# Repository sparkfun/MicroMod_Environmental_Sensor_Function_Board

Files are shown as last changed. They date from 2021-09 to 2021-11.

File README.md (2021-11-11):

SparkFun MicroMod Environmental Sensor Function Board
========================================

SparkFun MicroMod Environmental Sensor Function Board (https://www.sparkfun.com/products/18632)

[*SparkFun MicroMod Environmental Sensor Function Board (SEN-18632)*](https://www.sparkfun.com/products/18632)

The SparkFun MicroMod Environmental Function Board adds additional sensing options to the MicroMod Processor Boards. This Function Board includes three sensors to monitor air quality (SGP40), humidity & temperature (SHTC3), and CO<sub>2</sub> concentrations (STC31) in your indoor environment. To make it even easier to use, all communication is over the MicroMod's I<sup>2</sup>C bus!

* The SGP40 measures the quality of the air in your room or house. The SGP40 uses a metal oxide (MOx) sensor with a temperature controlled micro hotplate and provides a humidity-compensated volatile organic compound (VOC) based indoor air quality signal. Both the sensing element and VOC Algorithm feature an unmatched robustness against contaminating gases present in real world applications enabling a unique long term stability as well as low drift and device to device variation.

* The SHTC3 is a highly accurate digital humidity and temperature sensor. The SHTC3 uses a capacitive humidity sensor with a relative humidity measurement range of 0 to 100% RH and bandgap temperature sensor with a temperature measurement range of -40&deg;C to 125&deg;C. The SHTC3 builds on the success of their SHTC1 sensor with higher accuracy (±2% RH, ±0.2&deg;C) than its predecessor, enabling greater flexibility.

* The STC31 measures CO<sub>2</sub> concentrations based on thermal conductivity and has two CO<sub>2</sub> measurement ranges: 0 to 25 vol%; and 0 to 100 vol%. The measurement repeatability is 0.2 vol%, with a stability of 0.025 vol% / °C. The measurement accuracy depends on the measurement range: 0.5 vol% + 3% measured value; 1 vol% + 3% measured value. Using measurements from the SHTC3, the STC31 is able to provide humidity-compensated measurements together with improved temperature compensation.  The STC31 can compensate for atmospheric pressure too - which is handy if, like us, you’re up in the mountains!

The outstanding performance of these three sensors is based on Sensirion’s patented CMOSens<sup>&reg;</sup> technology, which combines the sensor element, signal processing, and digital calibration on a small CMOS chip. The well-proven CMOS technology is perfectly suited for high-quality mass production and is the ideal choice for demanding and cost-sensitive OEM applications.

Utilizing our handy M.2 MicroMod connector, no soldering is required to connect it to your system. Simply match up the key on your processor and function board's beveled edge connector to their respective key on the M.2 connector, then secure them to the main board with screws. The MicroMod Environmental Function Board can then be read via the I<sup>2</sup>C port. The board is equipped with the AP2112 3.3V voltage regulator, I<sup>2</sup>C pull-up resistors, power LED, jumper to disable the LED, and jumpers for alternative STC31 addresses. 

Repository Contents
-------------------

* **/Firmware** - Arduino example code from the tutorial
* **/Hardware** - Eagle design files (.brd, .sch)
* **/Production** - Production panel files (.brd)

Documentation
--------------

* **[Installing an Arduino Library Guide](https://learn.sparkfun.com/tutorials/installing-an-arduino-library/all)** - Basic information on how to install an Arduino library.
* **Arduino Libraries**
  * **[SGP40](https://github.com/sparkfun/SparkFun_SGP40_Arduino_Library)**
  * **[SHTC3](https://github.com/sparkfun/SparkFun_SHTC3_Arduino_Library)**
  * **[STC3X](https://github.com/sparkfun/SparkFun_STC3x_Arduino_Library)**
* **[Hookup Guide](https://learn.sparkfun.com/tutorials/2001)** - Basic hookup guide

Product Versions
----------------

* [SEN-18632](https://www.sparkfun.com/products/18632)- Initial release

Version History
---------------

* v1.0 - Initial Release

License Information
-------------------

This product is _**open source**_! 

Please review the LICENSE.md file for license information. 

If you have any questions or concerns on licensing, please contact technical support on our [SparkFun forums](https://forum.sparkfun.com/viewforum.php?f=152).

Distributed as-is; no warranty is given.

- Your friends at SparkFun.

_<COLLABORATION CREDIT>_

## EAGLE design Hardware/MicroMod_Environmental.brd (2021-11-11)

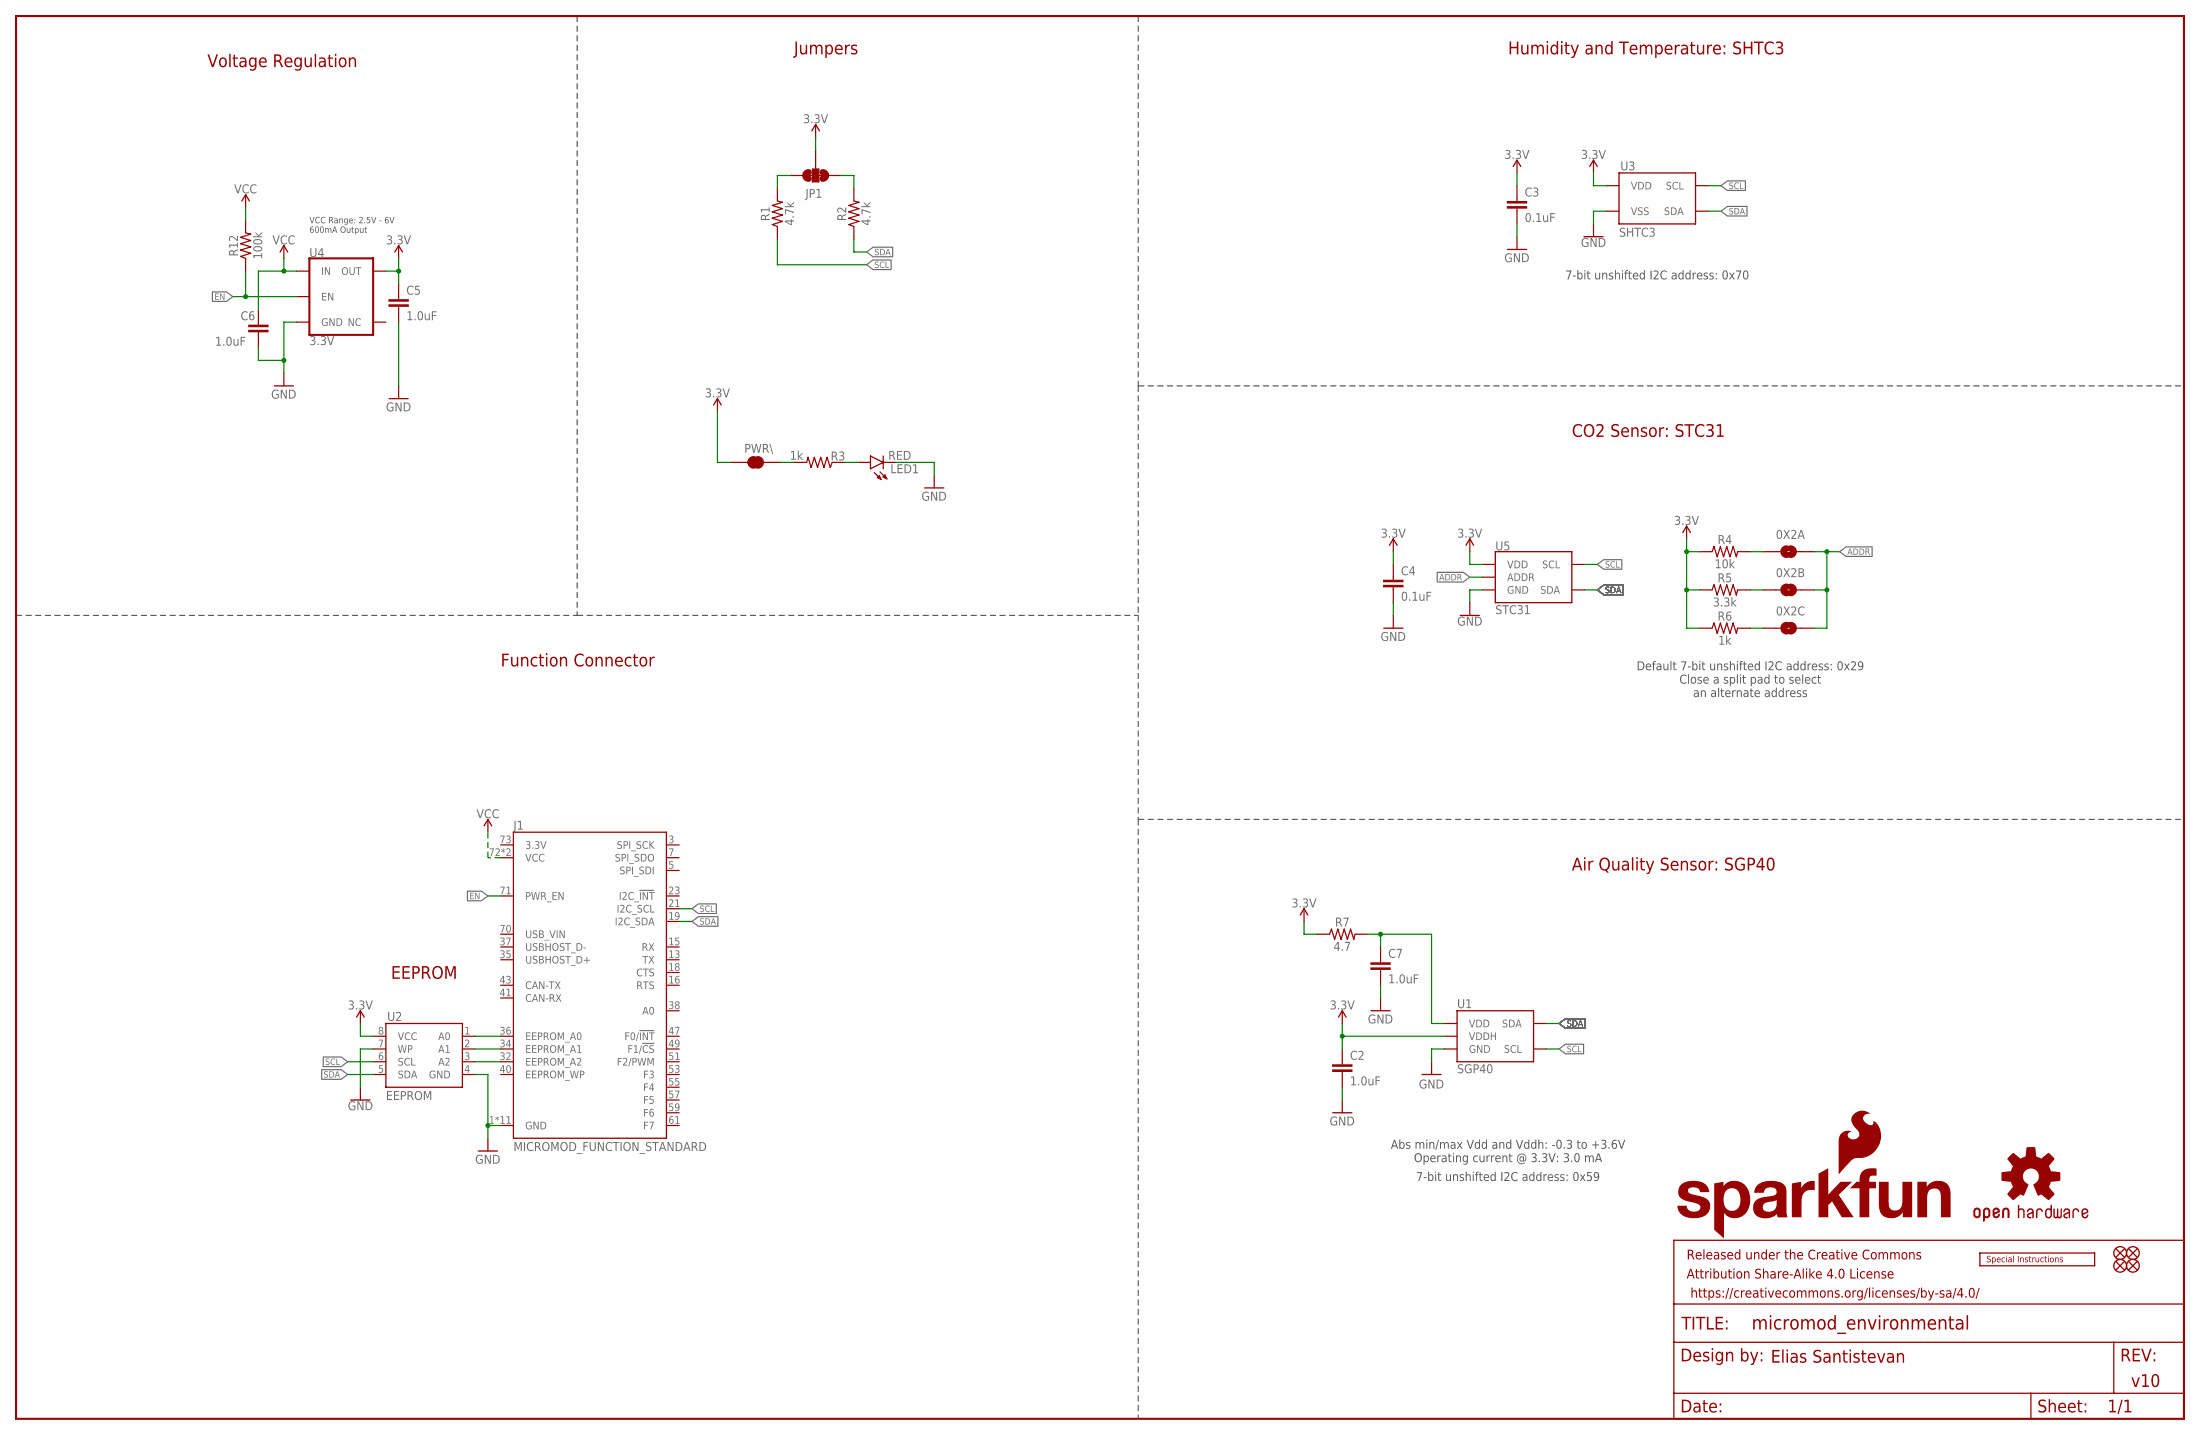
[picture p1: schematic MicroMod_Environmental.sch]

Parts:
0X2A, 0X2B, 0X2C: JUMPER-SMT_2_NO_SILK; SMT-JUMPER_2_NO_SILK
C2, C5, C6, C7: 1.0uF; 0603
C3, C4: 0.1uF; 0603
FD1, FD2, FD3, FD4: FIDUCIAL1X2; FIDUCIAL-1X2
FRAME1: FRAME-LEDGER; CREATIVE_COMMONS
J1: MICROMOD_FUNCTION_STANDARD; M.2-CARD-E-22_FUNCTION_STANDARD
JP1: JUMPER-SMT_3_2-NC_TRACE_SILK; SMT-JUMPER_3_2-NC_TRACE_SILK
LED1: RED; LED-0603
LOGO1: SFE_LOGO_NAME_FLAME.2_INCH; SFE_LOGO_NAME_FLAME_.2
LOGO2: OSHW-LOGOS; OSHW-LOGO-S
LOGO3: SPECIAL_INSTRUCTIONS-ORDERING; ORDERING_INSTRUCTIONS
PWR\: JUMPER-SMT_2_NC_TRACE_SILK; SMT-JUMPER_2_NC_TRACE_SILK
R1, R2: 4.7k; 0603
R3, R6: 1k; 0603
R4: 10k; 0603
R5: 3.3k; 0603
R7: 4.7; 0603
R12: 100k; 0603
U1: SGP40
U2: EEPROM; SO08
U3: SHTC3
U4: 3.3V; SOT23-5
U5: STC31

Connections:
3.3V: C2.1, C3.1, C4.1, C5.1, JP1.2, PWR\.2, R4.1, R5.1, R6.1, R7.1, U1.5 (VDDH), U2.8 (VCC), U3.1 (VDD), U4.5 (OUT), U5.6 (VDD)
A0: J1.36 (EEPROM_A0), U2.1 (A0)
A1: J1.34 (EEPROM_A1), U2.2 (A1)
A2: J1.32 (EEPROM_A2), U2.3 (A2)
ADDR: 0X2A.2, 0X2B.2, 0X2C.2, U5.3 (ADDR)
EN: J1.71 (PWR_EN), R12.1, U4.3 (EN)
GND: C2.2, C3.2, C4.2, C5.2, C6.2, C7.2, J1.1 (GND), J1.33 (GND), J1.39 (GND), J1.45 (GND), J1.75 (GND), J1.GND1 (GND), J1.GND2 (GND), J1.GND3 (GND), J1.GND4 (GND), J1.GND5 (GND), J1.GND6 (GND), LED1.C, U1.2 (GND), U1.4 (GND), U1.DIEPAD (GND), U2.4 (GND), U2.7 (WP), U3.4 (VSS), U3.5 (VSS), U4.2 (GND), U5.1 (GND), U5.5 (GND), U5.9 (GND), U5.11 (GND), U5.DIEPAD (GND)
unnamed: PWR\.1, R3.2
unnamed: C7.1, R7.2, U1.1 (VDD)
unnamed: JP1.3, R1.2
unnamed: JP1.1, R2.2
unnamed: 0X2A.1, R4.2
unnamed: 0X2B.1, R5.2
unnamed: 0X2C.1, R6.2
unnamed: LED1.A, R3.1
SCL: J1.21 (I2C_SCL), R1.1, U1.6 (SCL), U2.6 (SCL), U3.2 (SCL), U5.4 (SCL)
SDA: J1.19 (I2C_SDA), R2.1, U1.3 (SDA), U2.5 (SDA), U3.3 (SDA), U5.7 (SDA)
VCC: C6.1, J1.72 (VCC), J1.74 (VCC), R12.2, U4.1 (IN)

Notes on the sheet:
Elias Santistevan
v10
VCC Range: 2.5V - 6V 600mA Output
Default 7-bit unshifted I2C address: 0x29 Close a split pad to select an alternate address
7-bit unshifted I2C address: 0x70
7-bit unshifted I2C address: 0x59
Abs min/max Vdd and Vddh: -0.3 to +3.6V Operating current @ 3.3V: 3.0 mA
EEPROM
Voltage Regulation
Jumpers
Humidity and Temperature: SHTC3
CO2 Sensor: STC31
Function Connector
Air Quality Sensor: SGP40

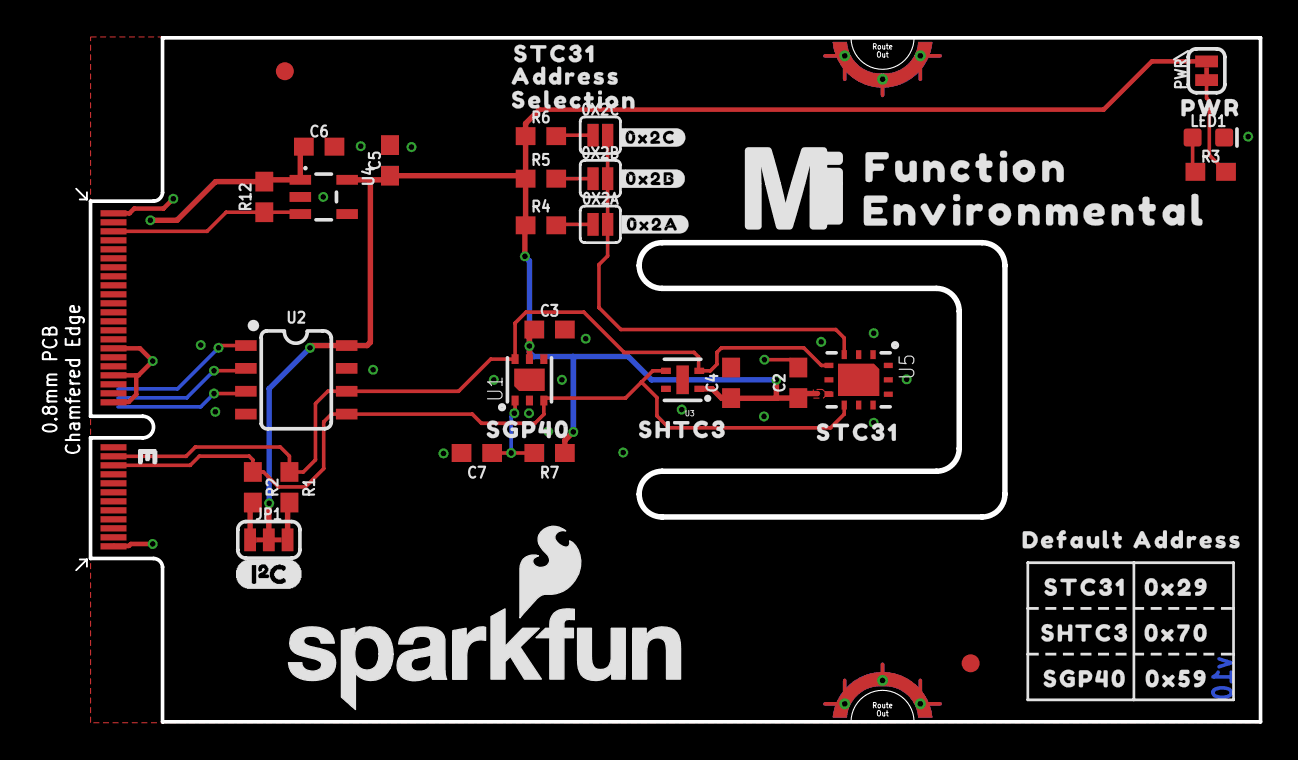
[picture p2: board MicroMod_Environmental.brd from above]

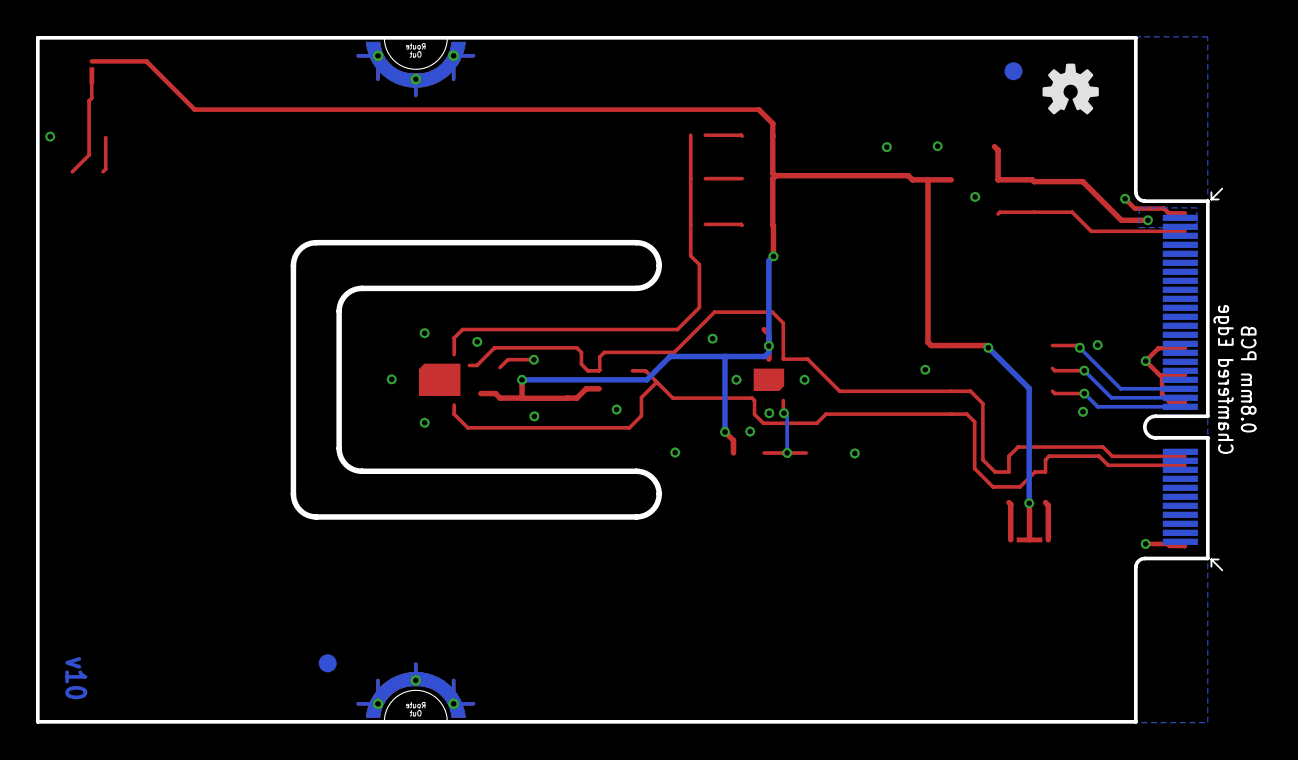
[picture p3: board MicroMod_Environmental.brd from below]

Board: 2 copper layers, 65.8 x 38.0 mm, 56 parts (3 on the bottom side), 18 nets.

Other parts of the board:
U$1: #0X2A#21
U$2: #0X2B#21
U$3: #0X2C#21
U$4: PWR321541
U$5: FUNCTION524
U$6: ENVIRONMENTAL526
U$7: MICROMOD_MI_LOGO_1
U$8: I2C
U$9, U$15: ADDRESS40313505
U$10: 0X2940313520
U$11, U$18: SGP40313503
U$12, U$17: SHTC3501
U$13, U$16, U$22: STC313502
U$14: DEFAULT40313504
U$19: 0X5940313520
U$20: 0X7040313520
U$21: SELECTION40313506

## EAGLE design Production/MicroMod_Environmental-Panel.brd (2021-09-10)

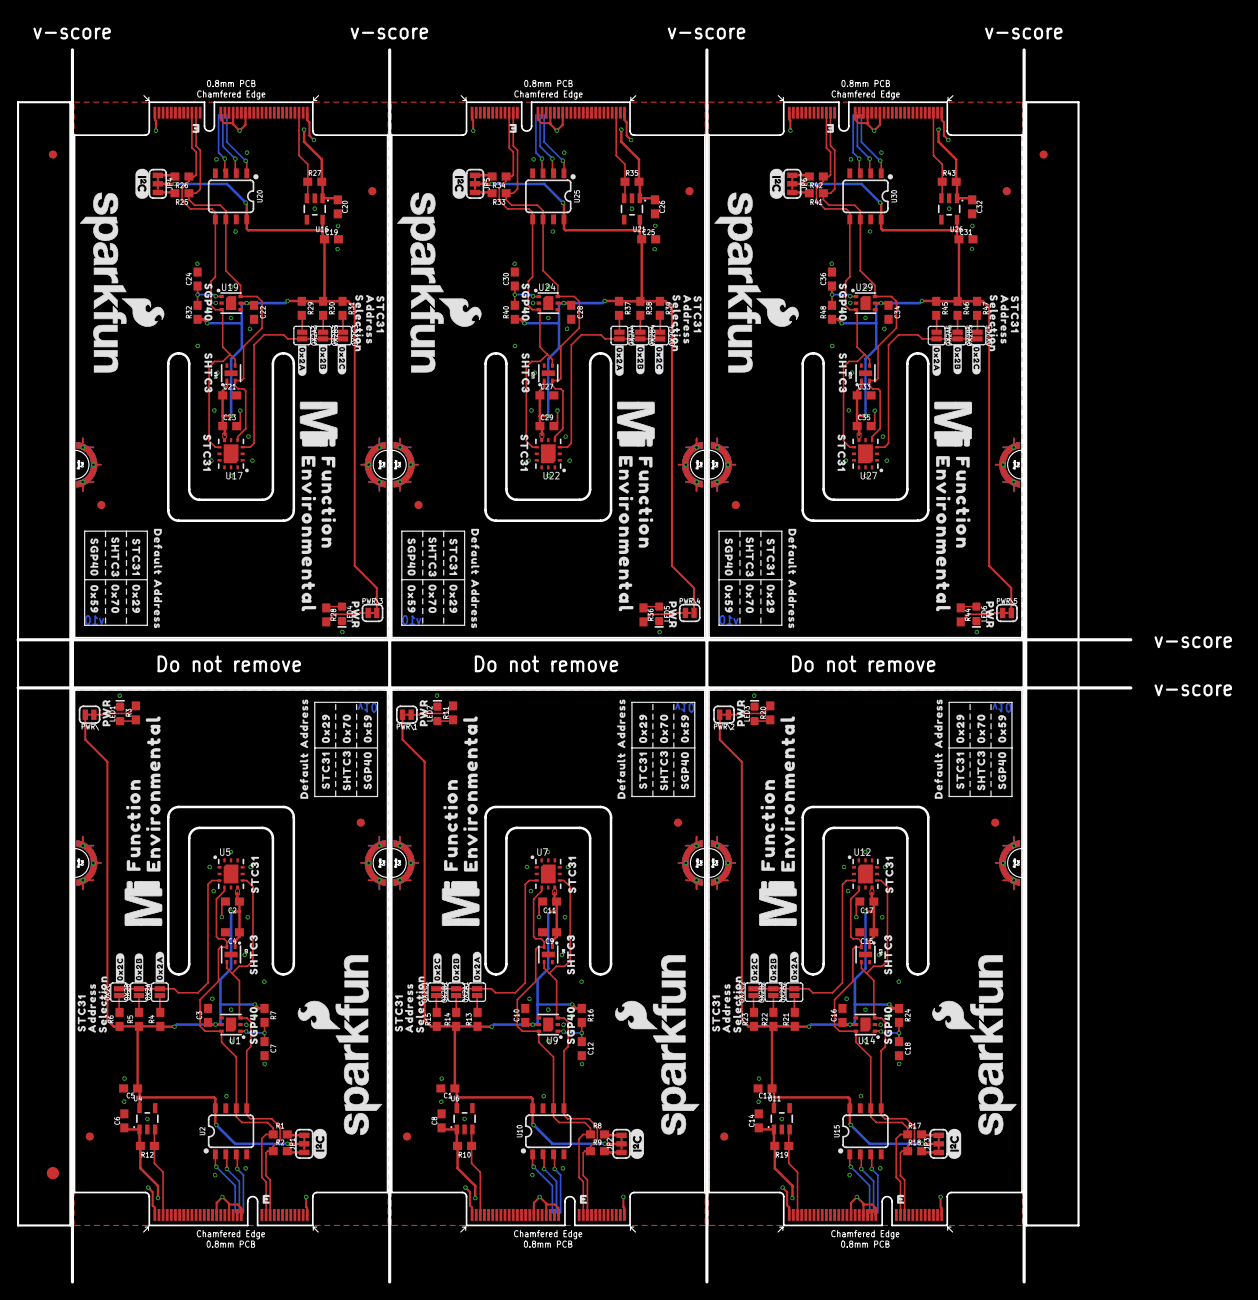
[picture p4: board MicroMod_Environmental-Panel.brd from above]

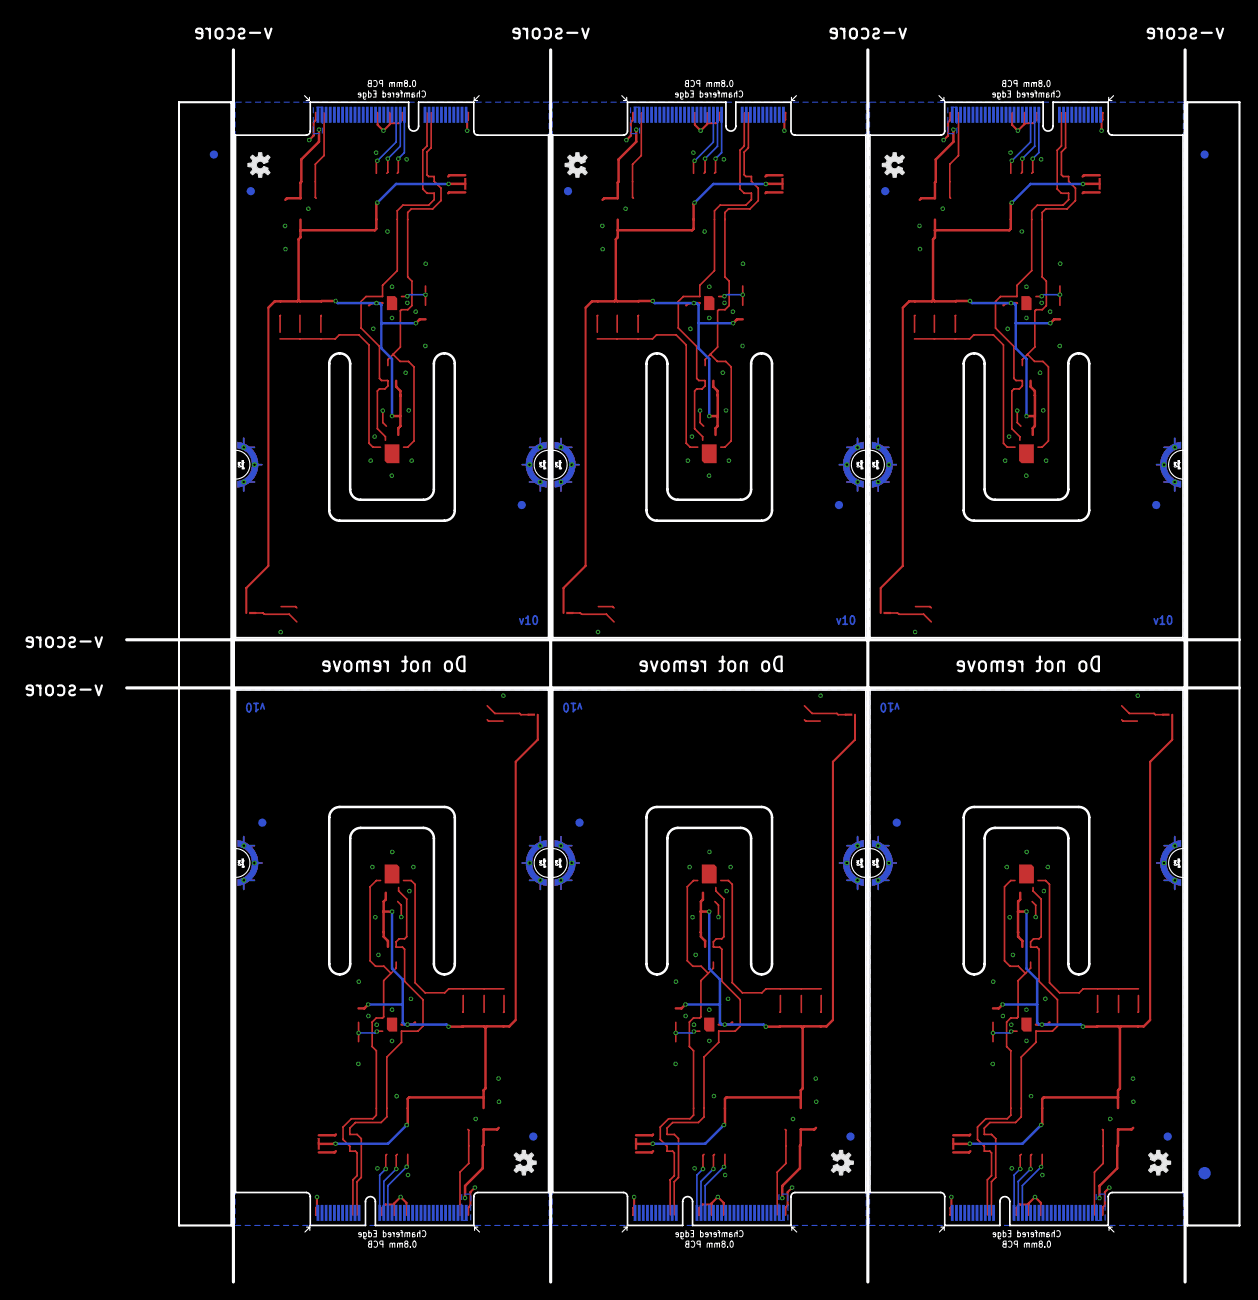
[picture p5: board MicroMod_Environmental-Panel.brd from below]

Board: 2 copper layers, 135.1 x 149.6 mm, 330 parts (21 on the bottom side), 108 nets.

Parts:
0X2A, 0X2A1, 0X2A2, 0X2A3, 0X2A4, 0X2A5, 0X2B, 0X2B1, 0X2B2, 0X2B3, 0X2B4, 0X2B5, 0X2C, 0X2C1, 0X2C2, 0X2C3, 0X2C4, 0X2C5: JUMPER-SMT_2_NO_SILK; SMT-JUMPER_2_NO_SILK
C1, C2, C5, C6, C7, C8, C11, C12, C13, C14, C17, C18, C19, C20, C23, C24, C25, C26, C29, C30, C31, C32, C35, C36: 1.0uF; 0603
C3, C4, C9, C10, C15, C16, C21, C22, C27, C28, C33, C34: 0.1uF; 0603
E$1, E$2, E$3, E$4: FIDUCIAL-1X2
E$5, E$6: FIDUCIAL-1.5X3
FD1, FD2, FD3, FD4, FD5, FD6, FD7, FD8, FD9, FD10, FD11, FD12, FD13, FD14, FD15, FD16, FD17, FD18, FD19, FD20, FD21, FD22, FD23, FD24: FIDUCIAL1X2; FIDUCIAL-1X2
J1, J2, J3, J4, J5, J6: MICROMOD_STANDARD; M.2-CARD-E-22_FUNCTION_STANDARD
JP1, JP2, JP3, JP4, JP5, JP6: JUMPER-SMT_3_2-NC_TRACE_SILK; SMT-JUMPER_3_2-NC_TRACE_SILK
LED1, LED2, LED3, LED4, LED5, LED6: RED; LED-0603
LOGO1, LOGO3, LOGO5, LOGO7, LOGO9, LOGO11: SFE_LOGO_NAME_FLAME.2_INCH; SFE_LOGO_NAME_FLAME_.2
LOGO2, LOGO4, LOGO6, LOGO8, LOGO10, LOGO12: OSHW-LOGOS; OSHW-LOGO-S
PWR\, PWR\1, PWR\2, PWR\3, PWR\4, PWR\5: JUMPER-SMT_2_NC_TRACE_SILK; SMT-JUMPER_2_NC_TRACE_SILK
R1, R2, R8, R9, R17, R18, R25, R26, R33, R34, R41, R42: 4.7k; 0603
R3, R6, R11, R15, R20, R23, R28, R31, R36, R39, R44, R47: 1k; 0603
R4, R13, R21, R29, R37, R45: 10k; 0603
R5, R14, R22, R30, R38, R46: 3.3k; 0603
R7, R16, R24, R32, R40, R48: 4.7; 0603
R10, R12, R19, R27, R35, R43: 100k; 0603
U1, U9, U14, U19, U24, U29: SGP40
U2, U10, U15, U20, U25, U30: EEPROM; SO08
U3, U8, U13, U18, U23, U28: SHTC3
U4, U6, U11, U16, U21, U26: 3.3V; SOT23-5
U5, U7, U12, U17, U22, U27: STC31
U$1, U$23, U$45, U$67, U$89, U$111: #0X2A#21
U$2, U$24, U$46, U$68, U$90, U$112: #0X2B#21
U$3, U$25, U$47, U$69, U$91, U$113: #0X2C#21
U$4, U$26, U$48, U$70, U$92, U$114: PWR321541
U$5, U$27, U$49, U$71, U$93, U$115: FUNCTION524
U$6, U$28, U$50, U$72, U$94, U$116: ENVIRONMENTAL526
U$7, U$29, U$51, U$73, U$95, U$117: MICROMOD_MI_LOGO_1
U$8, U$30, U$52, U$74, U$96, U$118: I2C
U$9, U$15, U$35, U$42, U$57, U$64, U$79, U$86, U$101, U$108, U$123, U$130: ADDRESS40313505
U$10, U$39, U$61, U$83, U$105, U$127: 0X2940313520
U$11, U$18, U$31, U$38, U$53, U$60, U$75, U$82, U$97, U$104, U$119, U$126: SGP40313503
U$12, U$17, U$32, U$37, U$54, U$59, U$76, U$81, U$98, U$103, U$120, U$125: SHTC3501
U$13, U$16, U$22, U$33, U$36, U$44, U$55, U$58, U$66, U$77, U$80, U$88, U$99, U$102, U$110, U$121, U$124, U$132: STC313502
U$14, U$34, U$56, U$78, U$100, U$122: DEFAULT40313504
U$19, U$40, U$62, U$84, U$106, U$128: 0X5940313520
U$20, U$41, U$63, U$85, U$107, U$129: 0X7040313520
U$21, U$43, U$65, U$87, U$109, U$131: SELECTION40313506

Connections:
3.3V: C2.1, C3.1, C4.1, C5.1, JP1.2, PWR\.2, R4.1, R5.1, R6.1, R7.1, U1.5, U2.8, U3.1, U4.5, U5.6
3.3V1: C1.1, C9.1, C10.1, C11.1, JP2.2, PWR\1.2, R13.1, R14.1, R15.1, R16.1, U6.5, U7.6, U8.1, U9.5, U10.8
3.3V2: C13.1, C15.1, C16.1, C17.1, JP3.2, PWR\2.2, R21.1, R22.1, R23.1, R24.1, U11.5, U12.6, U13.1, U14.5, U15.8
3.3V3: C19.1, C21.1, C22.1, C23.1, JP4.2, PWR\3.2, R29.1, R30.1, R31.1, R32.1, U16.5, U17.6, U18.1, U19.5, U20.8
3.3V4: C25.1, C27.1, C28.1, C29.1, JP5.2, PWR\4.2, R37.1, R38.1, R39.1, R40.1, U21.5, U22.6, U23.1, U24.5, U25.8
3.3V5: C31.1, C33.1, C34.1, C35.1, JP6.2, PWR\5.2, R45.1, R46.1, R47.1, R48.1, U26.5, U27.6, U28.1, U29.5, U30.8
A0: J1.36, U2.1
A1: J1.34, U2.2
A2: J1.32, U2.3
A3: J2.36, U10.1
A4: J2.32, U10.3
A5: J2.34, U10.2
A6: J3.36, U15.1
A7: J3.32, U15.3
A8: J3.34, U15.2
A9: J4.36, U20.1
A10: J4.32, U20.3
A11: J4.34, U20.2
A12: J5.36, U25.1
A13: J5.32, U25.3
A14: J5.34, U25.2
A15: J6.36, U30.1
A16: J6.32, U30.3
A17: J6.34, U30.2
ADDR: 0X2A.2, 0X2B.2, 0X2C.2, U5.3
ADDR1: 0X2A1.2, 0X2B1.2, 0X2C1.2, U7.3
ADDR2: 0X2A2.2, 0X2B2.2, 0X2C2.2, U12.3
ADDR3: 0X2A3.2, 0X2B3.2, 0X2C3.2, U17.3
ADDR4: 0X2A4.2, 0X2B4.2, 0X2C4.2, U22.3
ADDR5: 0X2A5.2, 0X2B5.2, 0X2C5.2, U27.3
EN: J1.71, R12.1, U4.3
EN1: J2.71, R10.1, U6.3
EN2: J3.71, R19.1, U11.3
EN3: J4.71, R27.1, U16.3
EN4: J5.71, R35.1, U21.3
EN5: J6.71, R43.1, U26.3
GND: C2.2, C3.2, C4.2, C5.2, C6.2, C7.2, J1.1, J1.33, J1.39, J1.45, J1.75, J1.GND1, J1.GND2, J1.GND3, J1.GND4, J1.GND5, J1.GND6, LED1.C, U1.2, U1.4, U1.DIEPAD, U2.4, U2.7, U3.4, U3.5, U4.2, U5.1, U5.5, U5.9, U5.11, U5.DIEPAD
GND1: C1.2, C8.2, C9.2, C10.2, C11.2, C12.2, J2.1, J2.33, J2.39, J2.45, J2.75, J2.GND1, J2.GND2, J2.GND3, J2.GND4, J2.GND5, J2.GND6, LED2.C, U6.2, U7.1, U7.5, U7.9, U7.11, U7.DIEPAD, U8.4, U8.5, U9.2, U9.4, U9.DIEPAD, U10.4, U10.7
GND2: C13.2, C14.2, C15.2, C16.2, C17.2, C18.2, J3.1, J3.33, J3.39, J3.45, J3.75, J3.GND1, J3.GND2, J3.GND3, J3.GND4, J3.GND5, J3.GND6, LED3.C, U11.2, U12.1, U12.5, U12.9, U12.11, U12.DIEPAD, U13.4, U13.5, U14.2, U14.4, U14.DIEPAD, U15.4, U15.7
GND3: C19.2, C20.2, C21.2, C22.2, C23.2, C24.2, J4.1, J4.33, J4.39, J4.45, J4.75, J4.GND1, J4.GND2, J4.GND3, J4.GND4, J4.GND5, J4.GND6, LED4.C, U16.2, U17.1, U17.5, U17.9, U17.11, U17.DIEPAD, U18.4, U18.5, U19.2, U19.4, U19.DIEPAD, U20.4, U20.7
GND4: C25.2, C26.2, C27.2, C28.2, C29.2, C30.2, J5.1, J5.33, J5.39, J5.45, J5.75, J5.GND1, J5.GND2, J5.GND3, J5.GND4, J5.GND5, J5.GND6, LED5.C, U21.2, U22.1, U22.5, U22.9, U22.11, U22.DIEPAD, U23.4, U23.5, U24.2, U24.4, U24.DIEPAD, U25.4, U25.7
GND5: C31.2, C32.2, C33.2, C34.2, C35.2, C36.2, J6.1, J6.33, J6.39, J6.45, J6.75, J6.GND1, J6.GND2, J6.GND3, J6.GND4, J6.GND5, J6.GND6, LED6.C, U26.2, U27.1, U27.5, U27.9, U27.11, U27.DIEPAD, U28.4, U28.5, U29.2, U29.4, U29.DIEPAD, U30.4, U30.7
unnamed: PWR\.1, R3.2
unnamed: C7.1, R7.2, U1.1
unnamed: JP1.3, R1.2
unnamed: JP1.1, R2.2
unnamed: 0X2A.1, R4.2
unnamed: 0X2B.1, R5.2
unnamed: 0X2C.1, R6.2
unnamed: LED2.A, R11.1
unnamed: PWR\1.1, R11.2
unnamed: LED1.A, R3.1
unnamed: 0X2A1.1, R13.2
unnamed: 0X2B1.1, R14.2
unnamed: 0X2C1.1, R15.2
unnamed: C12.1, R16.2, U9.1
unnamed: JP2.3, R8.2
unnamed: JP2.1, R9.2
unnamed: LED3.A, R20.1
unnamed: PWR\2.1, R20.2
unnamed: 0X2A2.1, R21.2
unnamed: 0X2B2.1, R22.2
unnamed: 0X2C2.1, R23.2
unnamed: C18.1, R24.2, U14.1
unnamed: JP3.3, R17.2
unnamed: JP3.1, R18.2
unnamed: LED4.A, R28.1
unnamed: PWR\3.1, R28.2
unnamed: 0X2A3.1, R29.2
unnamed: 0X2B3.1, R30.2
unnamed: 0X2C3.1, R31.2
unnamed: C24.1, R32.2, U19.1
unnamed: JP4.3, R25.2
unnamed: JP4.1, R26.2
unnamed: LED5.A, R36.1
unnamed: PWR\4.1, R36.2
unnamed: 0X2A4.1, R37.2
unnamed: 0X2B4.1, R38.2
unnamed: 0X2C4.1, R39.2
unnamed: C30.1, R40.2, U24.1
unnamed: JP5.3, R33.2
unnamed: JP5.1, R34.2
unnamed: LED6.A, R44.1
unnamed: PWR\5.1, R44.2
unnamed: 0X2A5.1, R45.2
unnamed: 0X2B5.1, R46.2
unnamed: 0X2C5.1, R47.2
unnamed: C36.1, R48.2, U29.1
unnamed: JP6.3, R41.2
unnamed: JP6.1, R42.2
SCL: J1.21, R1.1, U1.6, U2.6, U3.2, U5.4
SCL1: J2.21, R8.1, U7.4, U8.2, U9.6, U10.6
SCL2: J3.21, R17.1, U12.4, U13.2, U14.6, U15.6
SCL3: J4.21, R25.1, U17.4, U18.2, U19.6, U20.6
SCL4: J5.21, R33.1, U22.4, U23.2, U24.6, U25.6
SCL5: J6.21, R41.1, U27.4, U28.2, U29.6, U30.6
SDA: J1.19, R2.1, U1.3, U2.5, U3.3, U5.7
SDA1: J2.19, R9.1, U7.7, U8.3, U9.3, U10.5
SDA2: J3.19, R18.1, U12.7, U13.3, U14.3, U15.5
SDA3: J4.19, R26.1, U17.7, U18.3, U19.3, U20.5
SDA4: J5.19, R34.1, U22.7, U23.3, U24.3, U25.5
SDA5: J6.19, R42.1, U27.7, U28.3, U29.3, U30.5
VCC: C6.1, J1.72, J1.74, R12.2, U4.1
VCC1: C8.1, J2.72, J2.74, R10.2, U6.1
VCC2: C14.1, J3.72, J3.74, R19.2, U11.1
VCC3: C20.1, J4.72, J4.74, R27.2, U16.1
VCC4: C26.1, J5.72, J5.74, R35.2, U21.1
VCC5: C32.1, J6.72, J6.74, R43.2, U26.1

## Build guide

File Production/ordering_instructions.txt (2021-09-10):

panel size, 129x137mm
PCB thickness, 0.8mm
number of layers, 2
soldermask color, Red
silkscreen color, White
oz copper, 1oz
finish, ENIG
stencils, top
pcs per panel, 6
min trace width, 0.2032mm / 0.0080in
min drill size, 0.3048mm / 0.0120in

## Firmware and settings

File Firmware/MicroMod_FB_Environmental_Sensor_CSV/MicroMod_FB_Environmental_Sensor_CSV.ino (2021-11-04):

/******************************************************************************

  WRITTEN BY: Ho Yun "Bobby" Chan
  @ SparkFun Electronics
  DATE: 10/19/2021
  GITHUB REPO: https://github.com/sparkfun/MicroMod_Environmental_Sensor_Function_Board
  DEVELOPMENT ENVIRONMENT SPECIFICS:
    Firmware developed using Arduino IDE v1.8.12

  ========== DESCRIPTION==========
  This example code combines example codes from the SHTC3, STC31, and SGP40 libraries.
  Most of the steps to obtain the measurements are the same as the example code.
  Generic object names were renamed (e.g. mySensor => mySGP40 and mySTC3x).

     Example 1: Basic Relative Humidity and Temperature Readings  w/ SHTC3; Written by Owen Lyke
     Example 2: PHT (SHTC3) Compensated CO2 Readings w/ STC31; Written by Paul Clark and based on earlier code by Nathan Seidle
     Example 1: Basic VOC Index w/ SGP40; Written by Paul Clark

  Open a Serial Monitor/Plotter at 115200 baud to view the readings!

  Note: You may need to wait about ~5 minutes after starting up the code before VOC index
  has any values.

  ========== HARDWARE CONNECTIONS ==========
  MicroMod Artemis Processor Board => MicroMod Main Board => MicroMod Environmental Function Board (with SHTC3, STC31, and SGP40)

  Feel like supporting open source hardware?
  Buy a board from SparkFun!
       MicroMod MicroMod Artemis Processor   | https://www.sparkfun.com/products/16401
       MicroMod Main Board - Single          | https://www.sparkfun.com/products/18575
       MicroMod Environmental Function Board | https://www.sparkfun.com/products/18632

  You can also get the sensors individually.
       SHTC3 | https://www.sparkfun.com/products/16467
       STC31 | https://www.sparkfun.com/products/18385
       SGP40 | https://www.sparkfun.com/products/17729

  LICENSE: This code is released under the MIT License (http://opensource.org/licenses/MIT)

******************************************************************************/



#include <Wire.h>

#include "SparkFun_SHTC3.h" //Click here to get the library: http://librarymanager/All#SparkFun_SHTC3
SHTC3 mySHTC3; // Create an object of the SHTC3 class

#include "SparkFun_STC3x_Arduino_Library.h" //Click here to get the library: http://librarymanager/All#SparkFun_STC3x
STC3x mySTC3x; // Create an object of the STC3x class

#include "SparkFun_SGP40_Arduino_Library.h" // Click here to get the library: http://librarymanager/All#SparkFun_SGP40
SGP40 mySGP40; //Create an object of the SGP40 class

float RH = 0.00; // Variable to keep track of SHTC3 temperature compensation for the STC31
float temperature = 0.00; // Variable to keep track of SHTC3 relative humidity compensation for the STC31

//Debug mode, comment one of these lines out using a syntax
//for a single line comment ("//"):
#define DEBUG 0     //0 = Output for Serial Plotter, CSV
//#define DEBUG 1     //1 = Output for Serial Monitor





void setup() {

  Serial.begin(115200);
  //while (!Serial) ; // Wait for Serial Monitor/Plotter to open for Processors with Native USB (i.e. SAMD51)


#if DEBUG
  Serial.println(F("Initializing Combined Example w/ SGP40, SHTC3, and STC31."));
#else
  Serial.println(F("RH,degF,degC,SHTC3_Valid,RH_Compensate_Valid,degC_Compensate_Valid,CO2%,STC31_Valid,VOC_Index"));
#endif

  Wire.begin();

  //mySTC3x.enableDebugging(); // Uncomment this line to get helpful debug messages on Serial
  //mySGP40.enableDebugging(); // Uncomment this line to print useful debug messages to Serial



  if (mySHTC3.begin() != SHTC3_Status_Nominal)
  {
#if DEBUG
    Serial.println(F("SHTC3 not detected. Please check wiring. Freezing..."));
#endif
    while (1)
      ; // Do nothing more
  }

  if (mySTC3x.begin() == false)
  {
#if DEBUG
    Serial.println(F("STC3x not detected. Please check wiring. Freezing..."));
#endif
    while (1)
      ; // Do nothing more
  }

  if (mySGP40.begin() == false)
  {
#if DEBUG
    Serial.println(F("SGP40 not detected. Check connections. Freezing..."));
#endif
    while (1)
      ; // Do nothing more
  }



  //We need to tell the STC3x what binary gas and full range we are using
  //Possible values are:
  //  STC3X_BINARY_GAS_CO2_N2_100   : Set binary gas to CO2 in N2.  Range: 0 to 100 vol%
  //  STC3X_BINARY_GAS_CO2_AIR_100  : Set binary gas to CO2 in Air. Range: 0 to 100 vol%
  //  STC3X_BINARY_GAS_CO2_N2_25    : Set binary gas to CO2 in N2.  Range: 0 to 25 vol%
  //  STC3X_BINARY_GAS_CO2_AIR_25   : Set binary gas to CO2 in Air. Range: 0 to 25 vol%
  if (mySTC3x.setBinaryGas(STC3X_BINARY_GAS_CO2_AIR_25) == false)
  {
#if DEBUG
    Serial.println(F("Could not set the binary gas! Freezing..."));
#endif
    while (1)
      ; // Do nothing more
  }



  //We can compensate for temperature and relative humidity using the readings from the SHTC3

  if (mySHTC3.update() != SHTC3_Status_Nominal) // Request a measurement
  {
#if DEBUG
    Serial.println(F("Could not read the RH and T from the SHTC3! Freezing..."));
#endif
    while (1)
      ; // Do nothing more
  }

  //In case the ‘Set temperature command’ has been used prior to the measurement command,
  //the temperature value given out by the STC31 will be that one of the ‘Set temperature command’.
  //When the ‘Set temperature command’ has not been used, the internal temperature value can be read out.
  temperature = mySHTC3.toDegC(); // "toDegC" returns the temperature as a floating point number in deg C
#if DEBUG
  Serial.print(F("Setting STC3x temperature to "));
  Serial.print(temperature, 2);
  Serial.print(",");
  Serial.print(F("C was "));
#endif

  if (mySTC3x.setTemperature(temperature) == false) {
#if DEBUG
    Serial.print(F("not "));
#endif
  }
#if DEBUG
  Serial.println(F("successful"));
#endif

  RH = mySHTC3.toPercent(); // "toPercent" returns the percent humidity as a floating point number

#if DEBUG
  Serial.print(F("Setting STC3x RH to "));
  Serial.print(RH, 2);
  Serial.print(",");
  Serial.print(F("% was "));
#endif

  if (mySTC3x.setRelativeHumidity(RH) == false) {
#if DEBUG
    Serial.print(F("not "));
#endif
  }
#if DEBUG
  Serial.println(F("successful"));
#endif



  //If we have a pressure sensor available, we can compensate for ambient pressure too.
  //As an example, let's set the pressure to 840 mbar (== SF Headquarters)
  uint16_t pressure = 840;

#if DEBUG
  Serial.print(F("Setting STC3x pressure to "));
  Serial.print(pressure);
  Serial.print(F("mbar was "));
#endif

  if (mySTC3x.setPressure(pressure) == false) {
#if DEBUG
    Serial.print(F("not "));
#endif
  }
#if DEBUG
  Serial.println(F("successful"));

  Serial.println(F("Note: Relative humidity and temperature compensation for the STC31 will be updated frequently in the main loop() function."));
#endif

} //end setup()





void loop() {


  //==============================
  //======DEBUG TURNED ON=========
  //==============================
#if DEBUG
  //==============================
  //==========READ SHTC3==========
  //==============================
  //minimum update rate = ~100Hz

  SHTC3_Status_TypeDef result = mySHTC3.update();           // Call "update()" to command a measurement, wait for measurement to complete, and update the RH and T members of the object

  RH = mySHTC3.toPercent();                                 // "toPercent" returns the percent humidity as a floating point number
  Serial.print(F("RH = "));
  Serial.print(RH);

  Serial.print(F("%, T = "));
  Serial.print(mySHTC3.toDegF());                           // "toDegF" return the temperature as a flaoting point number in deg F
  Serial.print(F(" deg F, "));

  temperature = mySHTC3.toDegC();                           // "toDegC" returns the temperature as a floating point number in deg C
  Serial.print(temperature);
  Serial.print(F(" deg C"));

  if (mySHTC3.lastStatus == SHTC3_Status_Nominal)           // You can also assess the status of the last command by checking the ".lastStatus" member of the object
  {
    Serial.println("");                                         //Sample data good, no need to output a message
  }
  else {
    Serial.print(F(",     Update failed, error: "));        //notify user if there is an error
    errorDecoder(mySHTC3.lastStatus);
    Serial.println("");
  }



  //==============================
  //==========READ STC31==========
  //==============================
  //minimum update rate = 1Hz


  if (mySTC3x.setRelativeHumidity(RH) == false)
    Serial.print(F("Unable to set STC31 Relative Humidity with SHTC3."));

  if (mySTC3x.setTemperature(temperature) == false)
    Serial.println(F("Unable to set STC31 Temperature with SHTC3."));


  Serial.print(F("CO2(%): "));

  if (mySTC3x.measureGasConcentration())                   // measureGasConcentration will return true when fresh data is available
  {
    Serial.println(mySTC3x.getCO2(), 2);
  }
  else
  {
    Serial.print(mySTC3x.getCO2(), 2);
    Serial.println(F(",     (old STC3 sample reading, STC31 was not able to get fresh data yet)"));  //output this note to indicate  when we are not able to obtain a new measurement
  }



  //==============================
  //==========READ SGP40==========
  //==============================
  //minimum update rate = 1Hz

  Serial.print(F("VOC Index is: "));
  Serial.println(mySGP40.getVOCindex()); //Get the VOC Index using the default RH (50%) and T (25C)





  //==============================
  //=====DEBUG TURNED OFF=========
  //==============================
#else
  //==============================
  //==========READ SHTC3==========
  //==============================
  //minimum update rate = ~100Hz

  SHTC3_Status_TypeDef result = mySHTC3.update();           // Call "update()" to command a measurement, wait for measurement to complete, and update the RH and T members of the object

  RH = mySHTC3.toPercent();
  Serial.print(RH);
  Serial.print(",");
  Serial.print(mySHTC3.toDegF());
  Serial.print(",");
  temperature = mySHTC3.toDegC();                           // "toDegC" returns the temperature as a floating point number in deg C
  Serial.print(temperature);
  Serial.print(",");

  if (mySHTC3.lastStatus == SHTC3_Status_Nominal)           // You can also assess the status of the last command by checking the ".lastStatus" member of the object
  {
    Serial.print("1");                                         //Sample data good, no need to output a message
    Serial.print(",");
  }
  else
  {
    Serial.print("0");                                         //Sample data bad, no need to output a message
    Serial.print(",");
  }



  //==============================
  //==========READ STC31==========
  //==============================
  //minimum update rate = 1Hz


  if (mySTC3x.setRelativeHumidity(RH) == false)
  {
    //Serial.print(F("Unable to set STC31 Relative Humidity with SHTC3."));
    Serial.print("0");
    Serial.print(",");
  }
  else
  {
    Serial.print("1");
    Serial.print(",");
  }

  if (mySTC3x.setTemperature(temperature) == false)
  {
    //Serial.println(F("Unable to set STC31 Temperature with SHTC3."));
    Serial.print("0");
    Serial.print(",");
  }
  else
  {
    Serial.print("1");
    Serial.print(",");
  }

  if (mySTC3x.measureGasConcentration())                   // measureGasConcentration will return true when fresh data is available
  {
    Serial.print(mySTC3x.getCO2(), 2);
    Serial.print(",");
    Serial.print("1");                                     //Fresh Data
    Serial.print(",");
  }
  else
  {
    Serial.print(mySTC3x.getCO2(), 2);
    Serial.print(",");
    Serial.print("0");                                     //Data not fresh
    Serial.print(",");
  }



  //==============================
  //==========READ SGP40==========
  //==============================
  //minimum update rate = 1Hz

  Serial.println(mySGP40.getVOCindex()); //Get the VOC Index using the default RH (50%) and T (25C)

#endif



  //================================
  //=========SPACE & DELAY==========
  //================================
  //Serial.println("");// Uncomment this line to add some space between readings for the Serial Monitor
  delay(1000); //Wait 1 second - the Sensirion VOC algorithm expects a sample rate of 1Hz

}//end loop()





void errorDecoder(SHTC3_Status_TypeDef message)                             // The errorDecoder function prints "SHTC3_Status_TypeDef" resultsin a human-friendly way
{
  switch (message)
  {
    case SHTC3_Status_Nominal : Serial.print("Nominal"); break;
    case SHTC3_Status_Error : Serial.print("Error"); break;
    case SHTC3_Status_CRC_Fail : Serial.print("CRC Fail"); break;
    default : Serial.print("Unknown return code"); break;
  }
}

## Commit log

2021-08-31 Small tweaks to traces
    [MicroMod_Environmental.brd, MicroMod_Environmental.sch]
2021-09-01 Adds silk, fiducials, and version number
    * Adds text to part boxes in schematic
    [MicroMod_Environmental.brd, MicroMod_Environmental.sch]
2021-09-07 Reroutes board
    [MicroMod_Environmental.brd, MicroMod_Environmental.sch]
2021-09-09 Adds Silk for default I2C address
    [MicroMod_Environmental.brd]
2021-09-09 Adds some vias, moves some silk
    [MicroMod_Environmental.brd]
2021-09-10 Adds address table in silk, adds a more symmetrical cutout around IC's, labels ICs in silk
    [MicroMod_Environmental.brd, MicroMod_Environmental.sch]
2021-09-10 Fixes air wire
    [MicroMod_Environmental.brd]
2021-09-10 Panel v10
    [MicroMod_Environmental-Panel.GBL, MicroMod_Environmental-Panel.GBO, MicroMod_Environmental-Panel.GBP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]
2021-09-13 Moves production files to correct loaction
    [MicroMod_Environmental-Panel.GBL, MicroMod_Environmental-Panel.GBO, MicroMod_Environmental-Panel.GBP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]
2021-10-15 Updates pullup resistor to 2.2k from 4.7k
    [MicroMod_Environmental.brd, MicroMod_Environmental.sch]
2021-11-03 Updates Function Board symbol
    [MicroMod_Environmental.brd, MicroMod_Environmental.sch]
2021-11-11 Updates function board symbol to new one in the official SFE eagle library repo
    [MicroMod_Environmental.brd, MicroMod_Environmental.sch]

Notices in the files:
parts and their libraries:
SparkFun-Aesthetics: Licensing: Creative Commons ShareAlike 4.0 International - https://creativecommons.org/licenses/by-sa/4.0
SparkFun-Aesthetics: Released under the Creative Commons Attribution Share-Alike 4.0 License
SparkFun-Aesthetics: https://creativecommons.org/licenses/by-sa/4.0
